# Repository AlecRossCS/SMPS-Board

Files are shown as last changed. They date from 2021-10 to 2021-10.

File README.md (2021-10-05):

# SMPS-Board
This is a Switch Mode Power Supply Board based on the LM2576, with output capibilities of 3.3-36V, 3A. 

### Design
this is designed to be an independent board to be the main power supply for most projects, it does not take mains input, input is meant to be either plugpack, or independent AC-DC Unit such as a Meanwell 24v, 300W supply and then transform it into 3.3V, 5V, or 12V. 
schematic_capture

this design uses the multifaceted nature of the LM2576, as it will work with the LM2576-ADJ, LM2576-HV, LM2576-F3.3, LM2576-F5, or LM2576-F12. This meant some concern had to be taken to allow it to work either with the Adjustable or fixed versions. Some of the design rules are taken from the APP notes of the TI version datasheet. it is also designed with input protection of a PMOSFET (rather than diode protection).
It is designed to take full use of all of the copper surface of the PCB, as all of the copper is paid for to produce anyway with large planes to carry current as well as heat.

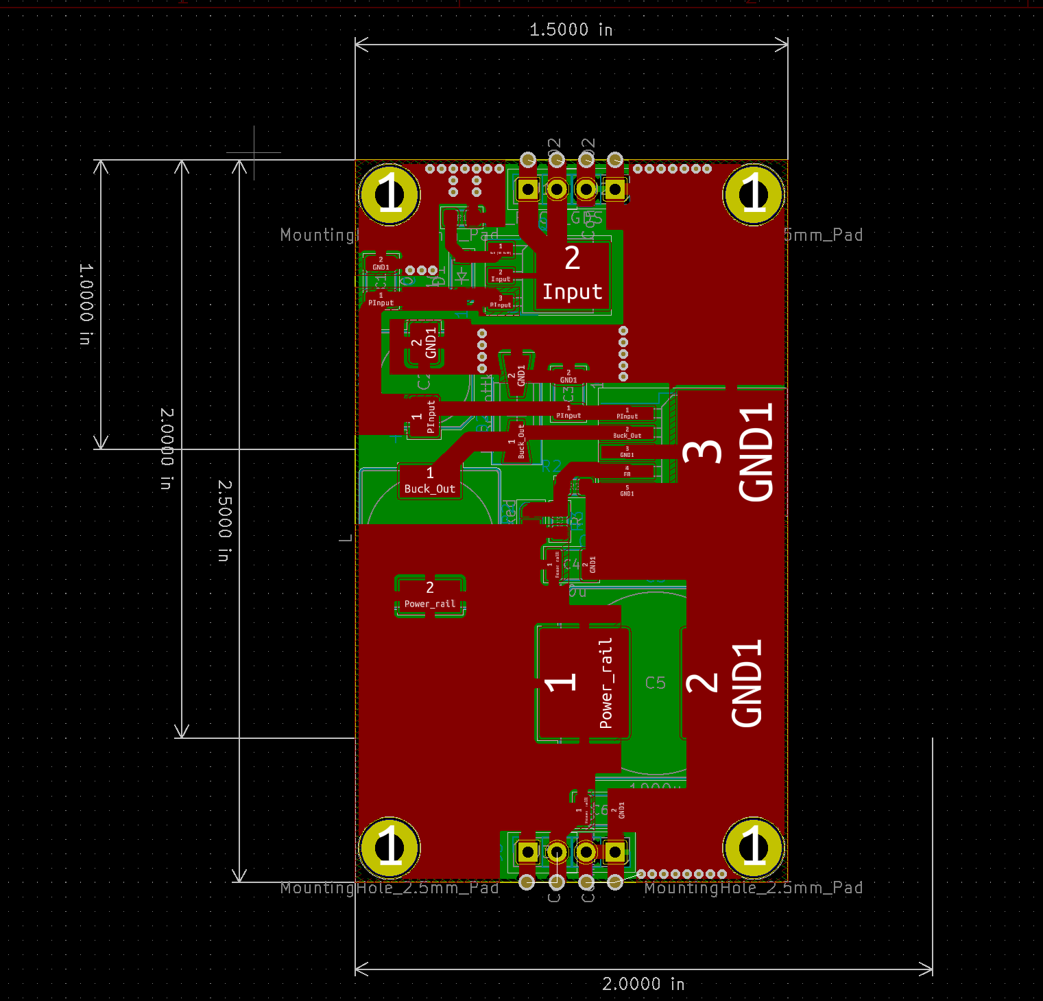
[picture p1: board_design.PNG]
board


mockup:

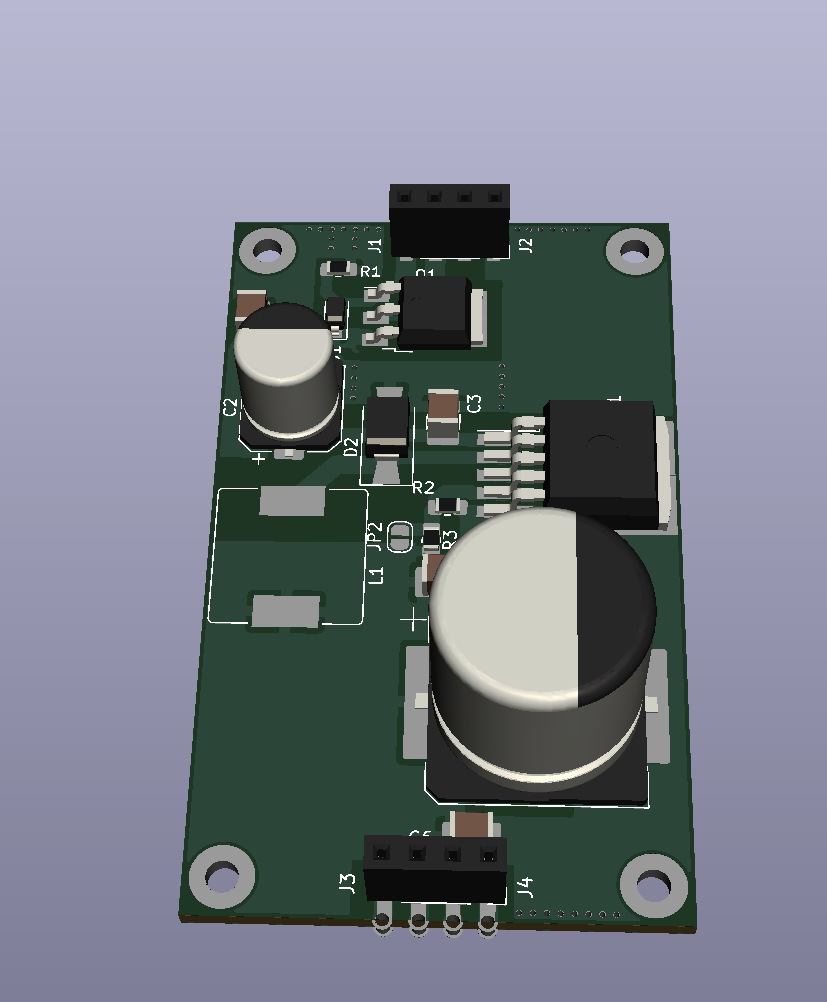
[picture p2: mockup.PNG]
mockup


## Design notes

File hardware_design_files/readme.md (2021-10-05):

### hardware design
all files created in kicad v5.10

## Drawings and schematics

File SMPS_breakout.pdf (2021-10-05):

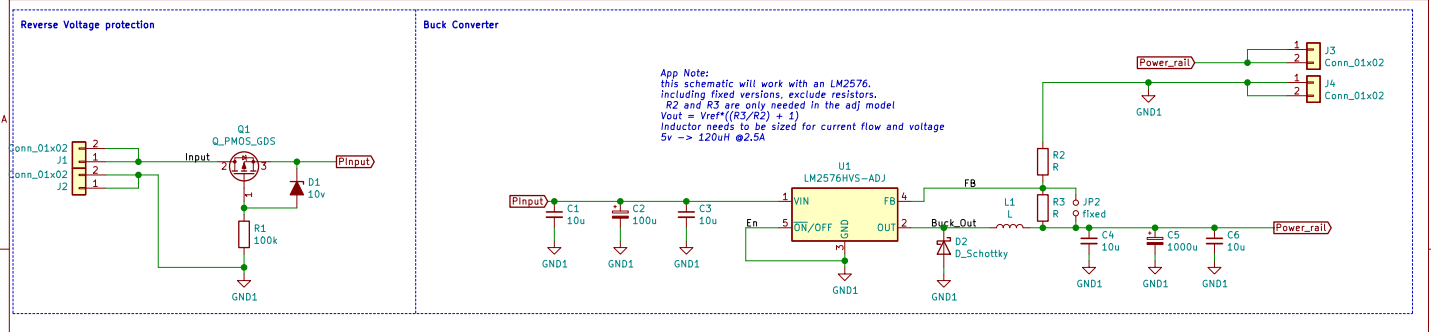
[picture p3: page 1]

5v -> 120uH @2.5A Reverse Voltage protection LM2576HVS-ADJ FB | Power_rail PInput Power_rail PInput Input

this schematic will work with an LM2576.
including fixed versions, exclude resistors.
R2 and R3 are only needed in the adj model
Vout = Vref*((R3/R2) + 1)
Inductor needs to be sized for current flow and voltage

File: SMPS_breakout.sch Sheet: / Alec R

Id: 1/1 Title: SMPS Board

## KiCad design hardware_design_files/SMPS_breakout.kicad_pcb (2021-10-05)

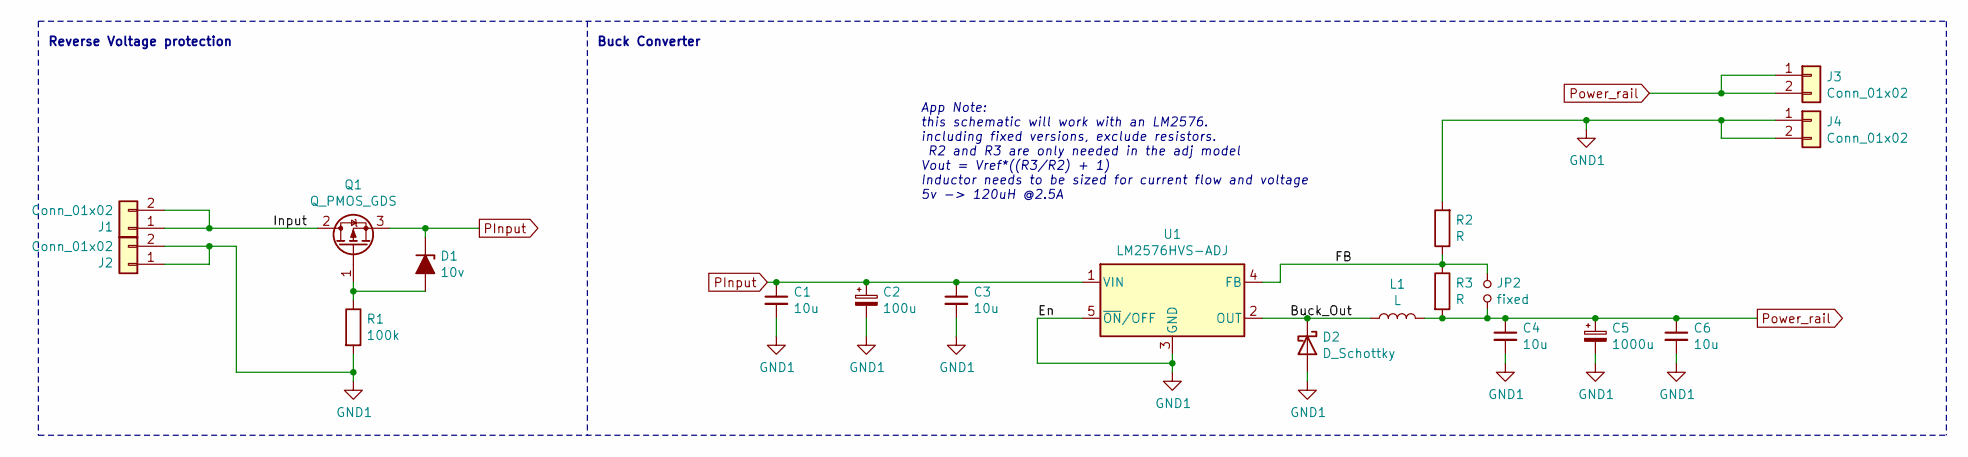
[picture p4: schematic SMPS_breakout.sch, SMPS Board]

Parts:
C1, C3, C4, C6: 10u; C_1210_3225Metric_Pad1.33x2.70mm_HandSolder
C2: 100u; CP_Elec_8x10
C5: 1000u; CP_Elec_16x17.5
D1: 10v; D_SOD-123
D2: D_Schottky; D_SMA-SMB_Universal_Handsoldering
J1, J2, J3, J4: Conn_01x02; PinSocket_1x02_P2.54mm_Vertical
JP2: fixed; SolderJumper-2_P1.3mm_Open_RoundedPad1.0x1.5mm
L1: L; L_Bourns_SRR1210A
Q1: Q_PMOS_GDS; TO-252-3_TabPin2
R1: 100k; R_0805_2012Metric_Pad1.20x1.40mm_HandSolder
R2, R3: R; R_0805_2012Metric_Pad1.20x1.40mm_HandSolder
U1: LM2576HVS-ADJ; TO-263-5_TabPin3

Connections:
/Buck_Out: D2.1 (K), L1.1, U1.2 (OUT)
/FB: JP2.1, R2.1, R3.1, U1.4 (FB)
/Input: J1.1, J1.2, Q1.2 (D)
GND1: C1.2, C2.2, C3.2, C4.2, C5.2, C6.2, D2.2 (A), J2.1, J2.2, J4.1, J4.2, R1.2, R2.2, U1.3 (GND), U1.5 (~ON~/OFF)
unnamed: D1.2 (A), Q1.1 (G), R1.1
PInput: C1.1, C2.1, C3.1, D1.1 (K), Q1.3 (S), U1.1 (VIN)
Power_rail: C4.1, C5.1, C6.1, J3.1, J3.2, JP2.2, L1.2, R3.2

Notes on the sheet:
Reverse Voltage protection
Buck Converter
App Note: this schematic will work with an LM2576. including fixed versions, exclude resistors. R2 and R3 are only needed in the adj model Vout = Vref*((R3/R2) + 1) Inductor needs to be sized for current flow and voltage 5v -> 120uH @2.5A

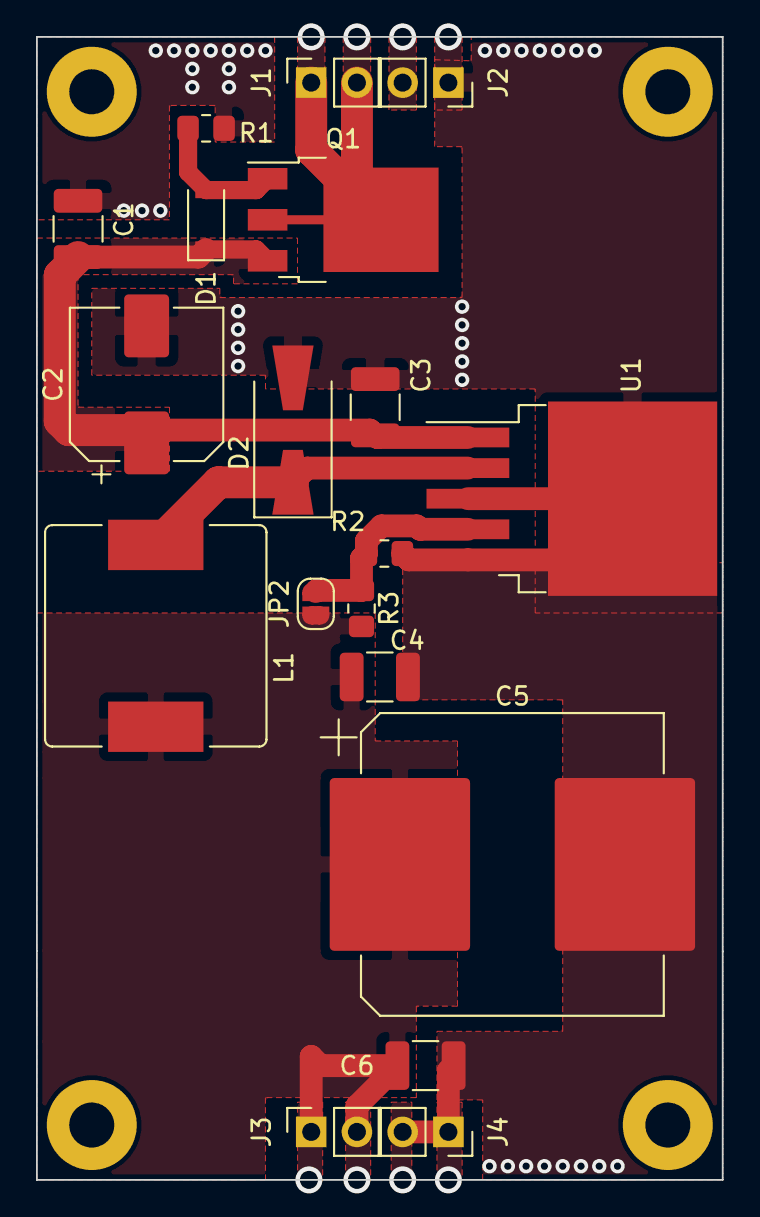
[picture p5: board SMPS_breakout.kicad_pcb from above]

Board: 2 copper layers, 38.1 x 63.5 mm, 23 parts (0 on the bottom side), 7 nets.

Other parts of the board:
 : MountingHole_2.5mm_Pad
 #2,  #3,  #4: MountingHole_2.5mm_Pad
